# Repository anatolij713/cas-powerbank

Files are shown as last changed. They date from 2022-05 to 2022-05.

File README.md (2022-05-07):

# Powerbank with Flashlight for Metabo/CAS 18V Battery pack
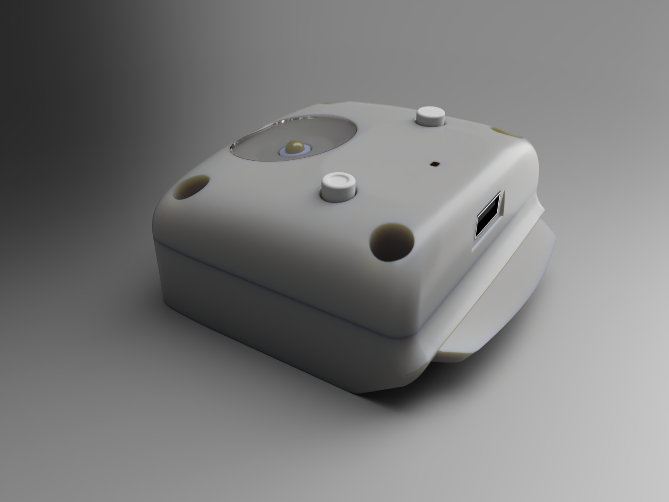
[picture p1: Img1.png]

## Required materials:
- "MH-KC24" DC-DC Step-Down Module
- Star type 20mm diameter Aluminium PCB with 1W LED
- Assembled Flashlight Board
- 2 pcs 1208YD Buttons
- 4 pcs Insert nuts M4x6mm
- 4 Screws M4x16
- 2 Springs about 6mm length and 4..6mm diameter
- 2 male Crimp Terminals 6.35x0.8mm
- Wires
- Some Glue:)

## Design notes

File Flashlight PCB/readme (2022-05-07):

Gerber.zip file can be used for PCB ordering at JLCPCB or another service.
Flashlight_PT4115-F_Cu.pdf or Flashlight_PT4115-F_Cu.svg - for homemade PCB, images are mirrored.

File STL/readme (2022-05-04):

Acryl Cap.stl and Acryl Indicator.stl must be printed with a transparent filament.

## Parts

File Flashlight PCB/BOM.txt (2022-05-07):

C1, C2  SMD 0805 capacitors             330nF .. 1uF, 50V
D1      SMD SMA Package Shottkey Diode  SS14 or another
L1      THT Inductor, min 300mA         68uH, for example, Bourns RLB0914-680KL
R1      THT Resistor                    about 0.47..0.51 Ohms
U1      Led Driver IC                   PT4115

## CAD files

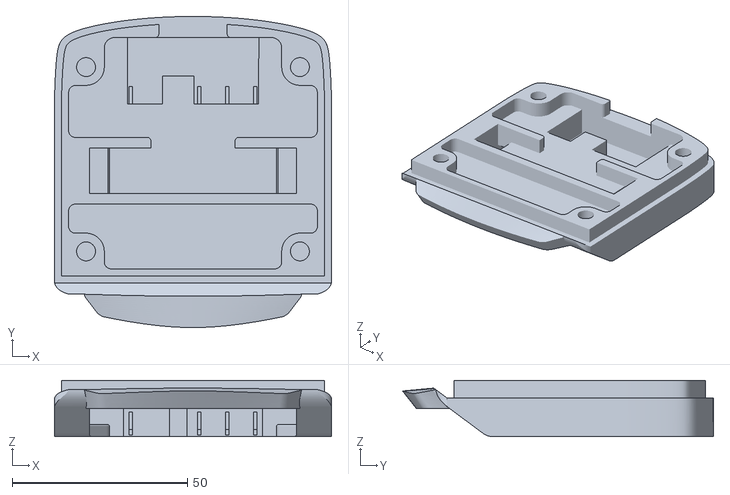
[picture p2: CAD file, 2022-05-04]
STL/Connector Main.stl
79.0 x 88.7 x 16.0

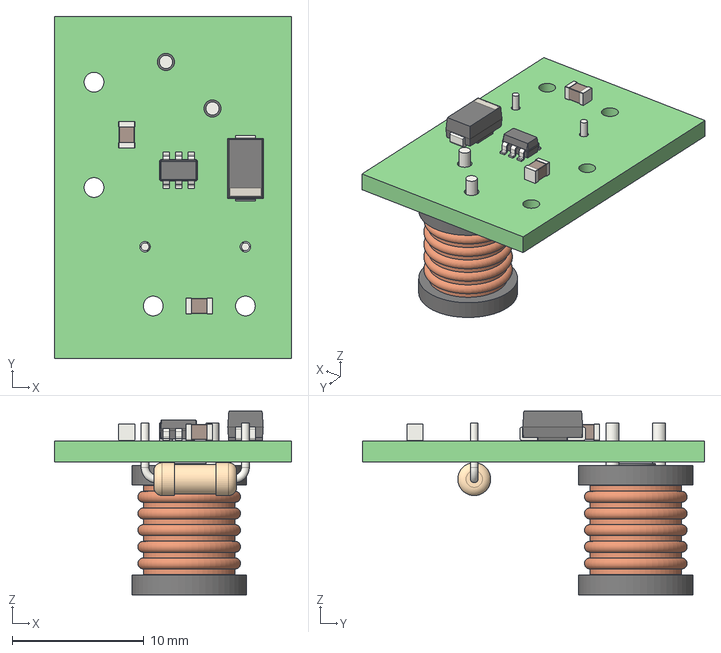
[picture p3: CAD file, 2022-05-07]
Flashlight PCB/Flashlight_PT4115.step
18.0 x 26.0 x 14.0 mm

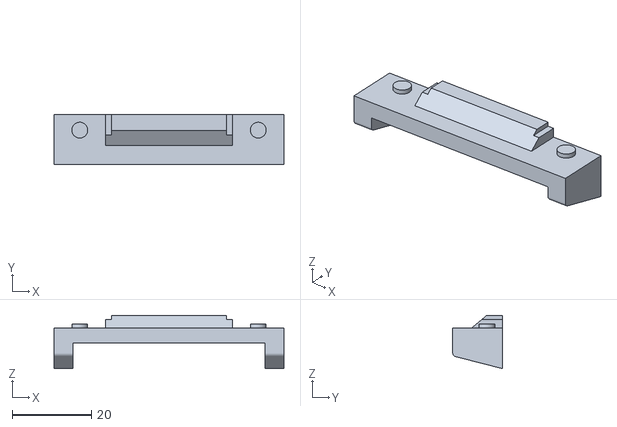
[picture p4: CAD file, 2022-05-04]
STL/Connector Lock.stl
58.0 x 12.5 x 13.4

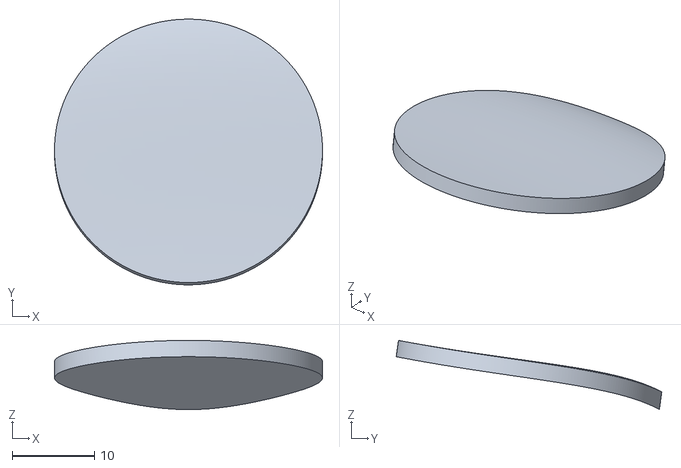
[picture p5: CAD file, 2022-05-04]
STL/Acryl Cap.stl
32.6 x 32.3 x 8.41

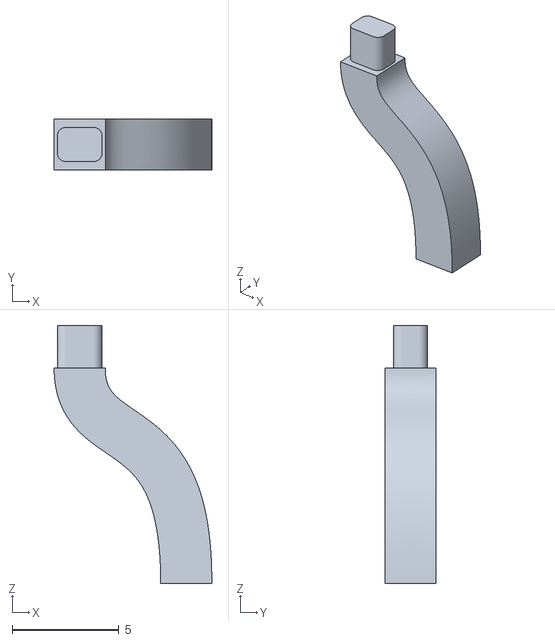
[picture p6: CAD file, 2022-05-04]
STL/Acryl Indicator.stl
7.40 x 2.40 x 12.1

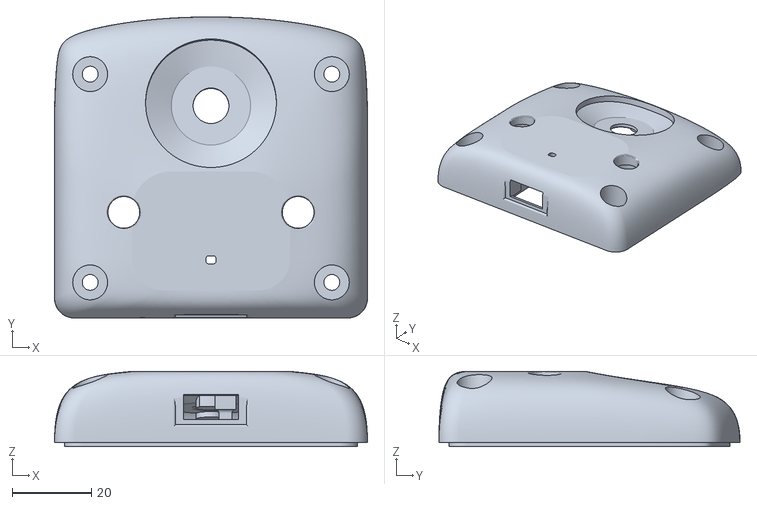
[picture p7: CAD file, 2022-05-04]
STL/Top Case.stl
79.0 x 76.0 x 19.0

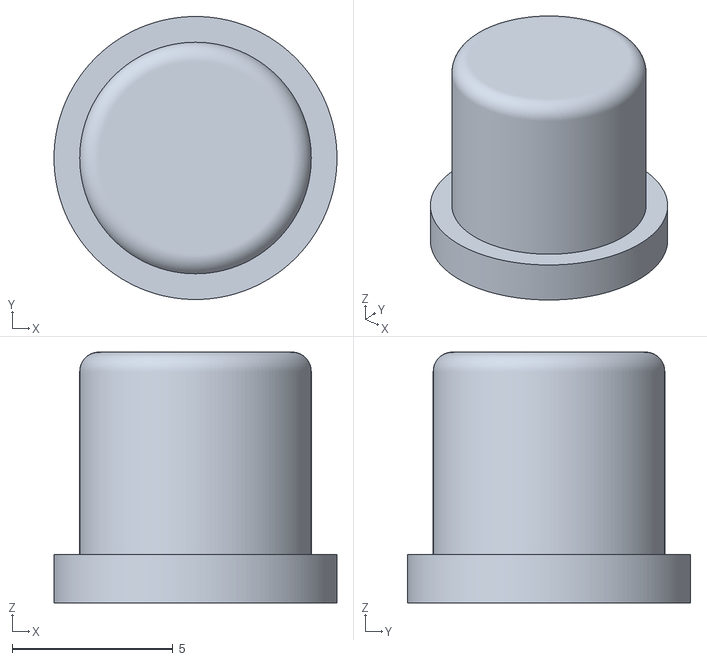
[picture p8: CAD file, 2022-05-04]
STL/Push Button 2.stl
8.80 x 8.80 x 7.80

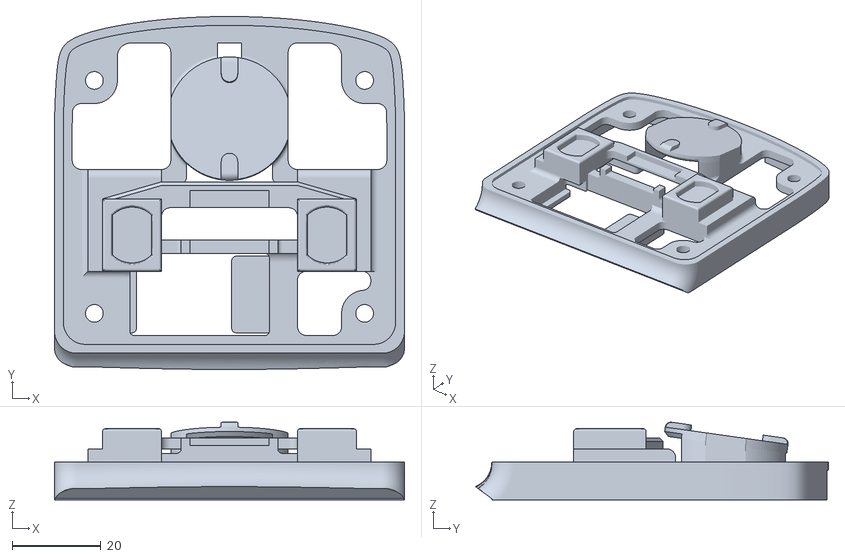
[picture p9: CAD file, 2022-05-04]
STL/Connector Int.stl
79.0 x 79.7 x 17.5

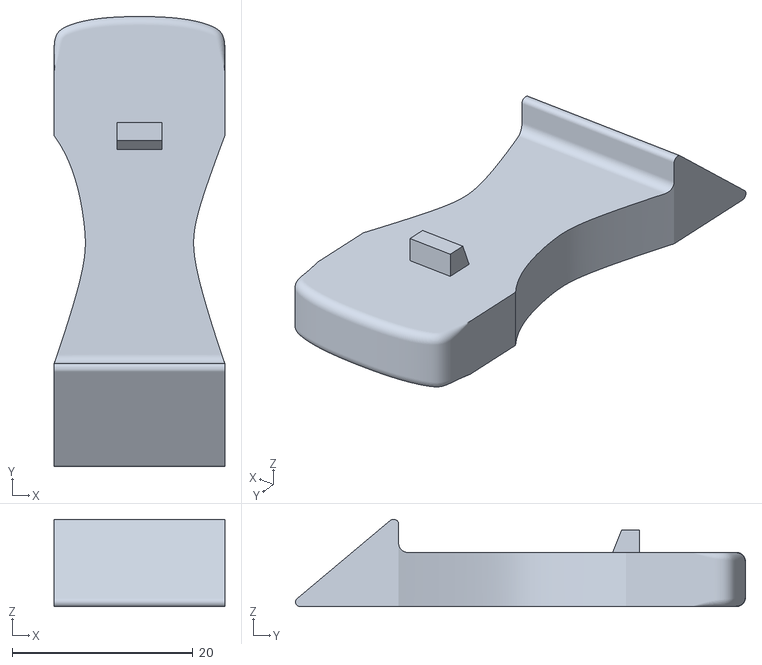
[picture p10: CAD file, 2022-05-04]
STL/Connector Push button.stl
18.9 x 49.9 x 9.65

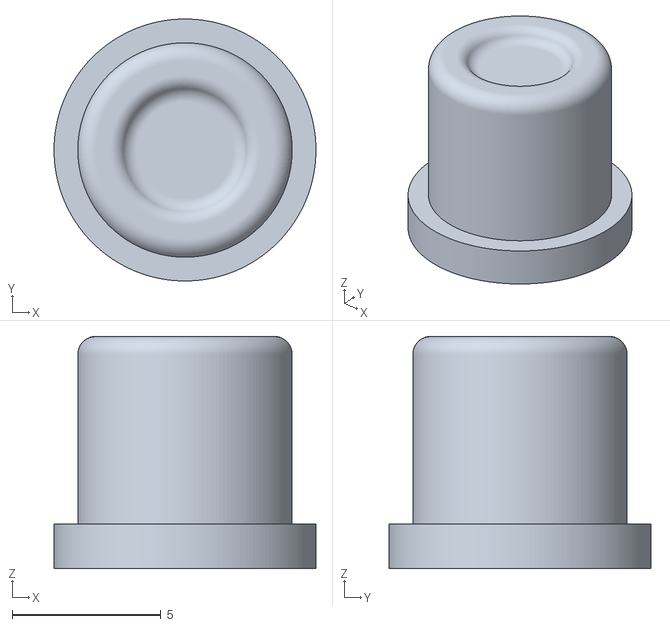
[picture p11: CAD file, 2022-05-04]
STL/Push Button 1.stl
8.80 x 8.80 x 7.80

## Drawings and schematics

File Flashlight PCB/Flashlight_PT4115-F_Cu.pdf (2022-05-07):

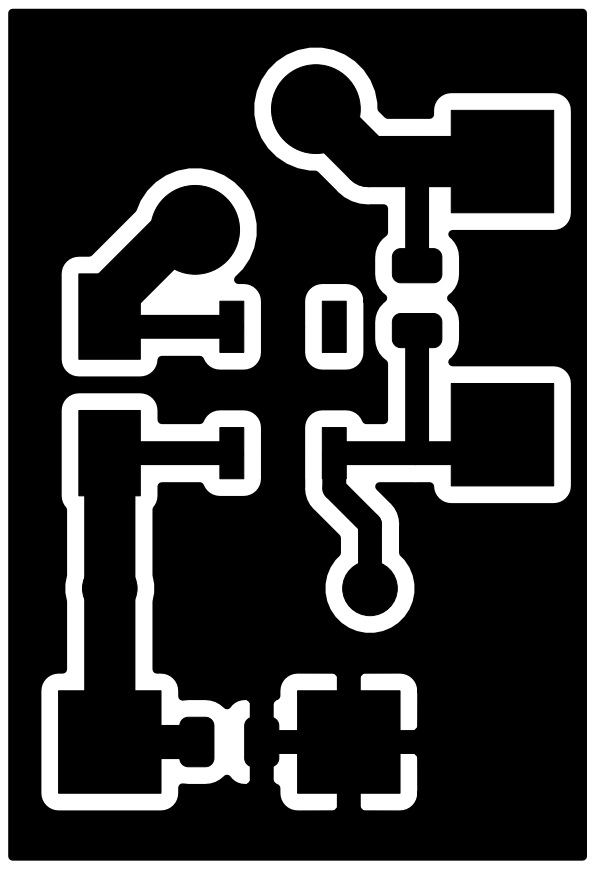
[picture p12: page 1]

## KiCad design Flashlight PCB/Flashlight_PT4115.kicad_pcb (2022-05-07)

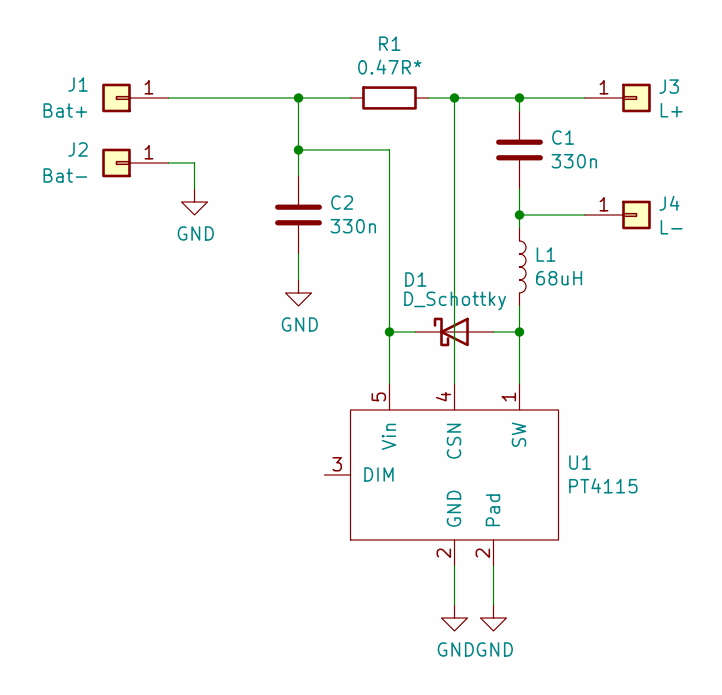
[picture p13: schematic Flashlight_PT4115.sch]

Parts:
C1, C2: 330n; C_0805_2012Metric
D1: D_Schottky; D_SMA
J1: Bat+; TestPoint_THTPad_3.0x3.0mm_Drill1.5mm
J2: Bat-; TestPoint_THTPad_3.0x3.0mm_Drill1.5mm
J3: L+; TestPoint_THTPad_3.0x3.0mm_Drill1.5mm
J4: L-; TestPoint_THTPad_3.0x3.0mm_Drill1.5mm
L1: 68uH; L_Radial_D8.7mm_P5.00mm_Fastron_07HCP
R1: 0.47R*; R_Axial_DIN0207_L6.3mm_D2.5mm_P7.62mm_Horizontal
U1: PT4115; SOT-89-5

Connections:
GND: C2.2, J2.1, U1.2 (GND)
unnamed: C1.1, J3.1, R1.1, U1.4 (CSN)
unnamed: C1.2, J4.1, L1.1
unnamed: C2.1, D1.1 (K), J1.1, R1.2, U1.5 (Vin)
unnamed: D1.2 (A), L1.2, U1.1 (SW)

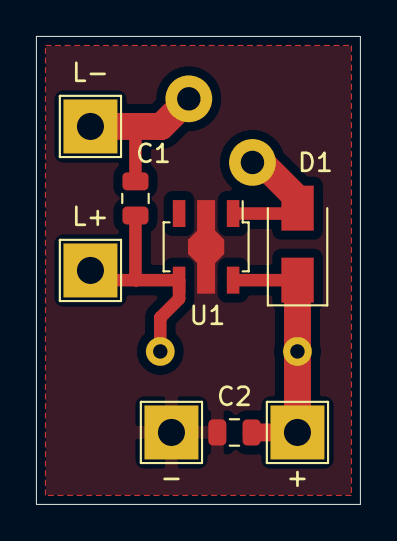
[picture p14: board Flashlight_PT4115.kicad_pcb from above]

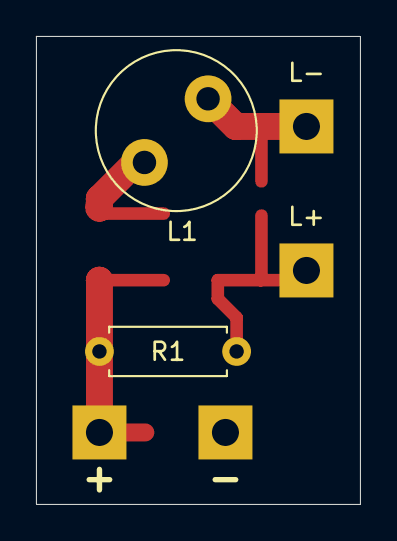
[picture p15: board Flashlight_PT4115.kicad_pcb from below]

Board: 2 copper layers, 18.0 x 26.0 mm, 10 parts (2 on the bottom side), 5 nets.
